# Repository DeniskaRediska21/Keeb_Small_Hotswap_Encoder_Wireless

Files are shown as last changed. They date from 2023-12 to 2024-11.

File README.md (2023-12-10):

# Split Ergo Ortholinear Hotswap Keyboard 

This project attempts to create easelly reproducible split ortholinear  hotswap mechanical
keyboard. 

Gimmics: 
+ This design doesn't require any diodes
+ Uses PiPico as MC, runs on CircuitPython
+ Key layouts are changed by dragging a file onto PiPicos storrage
+ Halves are connected through TypeC
+ PCB fits into 100x100mm square, so it is very cheap to order from Chineese manifacturers

# Gallery

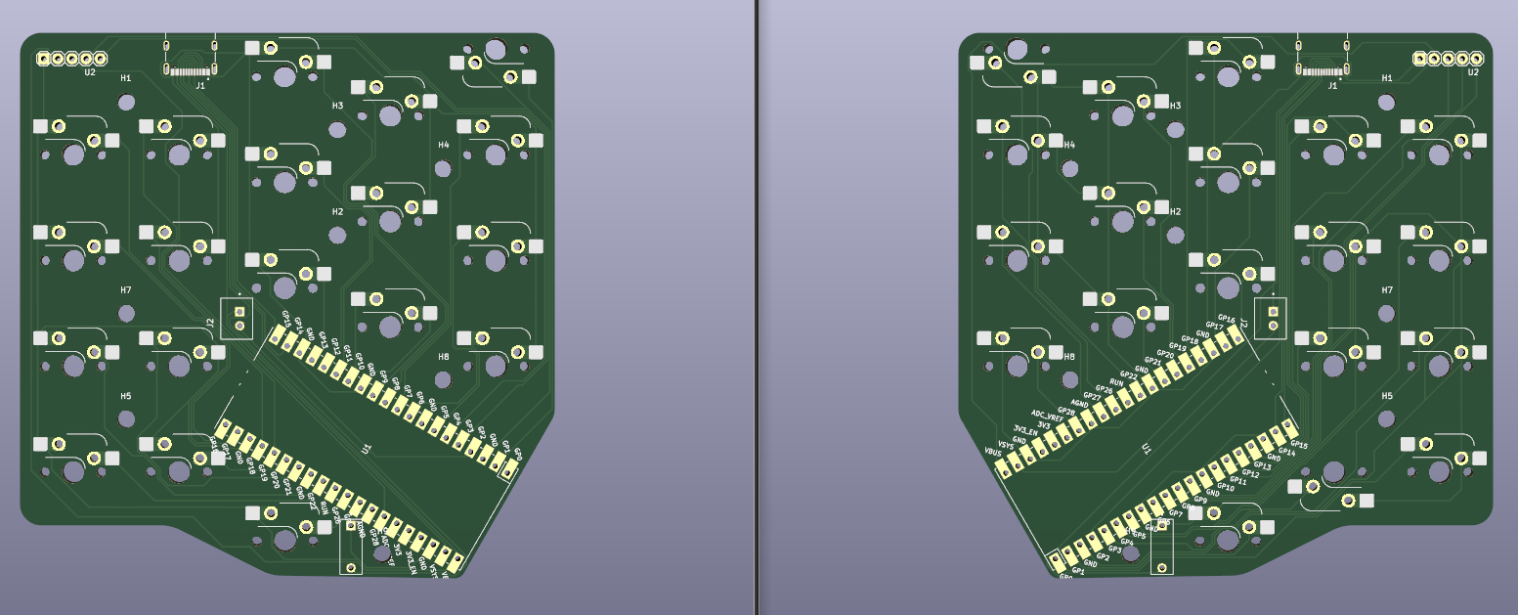
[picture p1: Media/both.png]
PCB


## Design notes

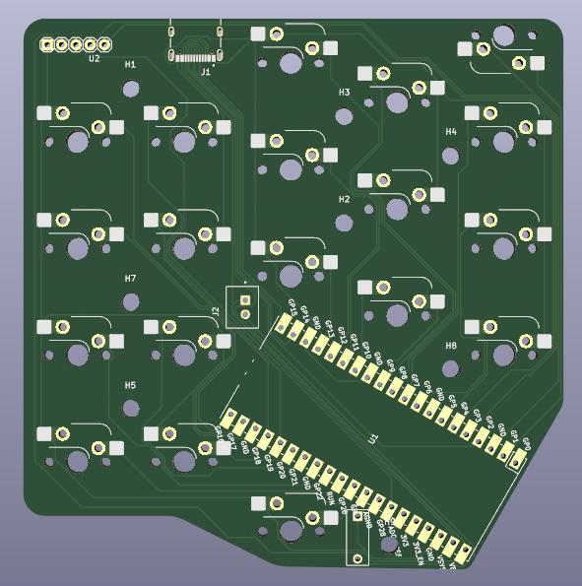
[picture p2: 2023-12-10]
Media/left_board.png

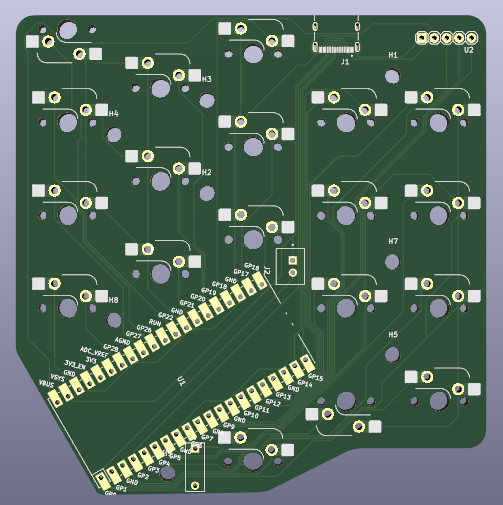
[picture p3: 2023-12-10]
Media/right.png

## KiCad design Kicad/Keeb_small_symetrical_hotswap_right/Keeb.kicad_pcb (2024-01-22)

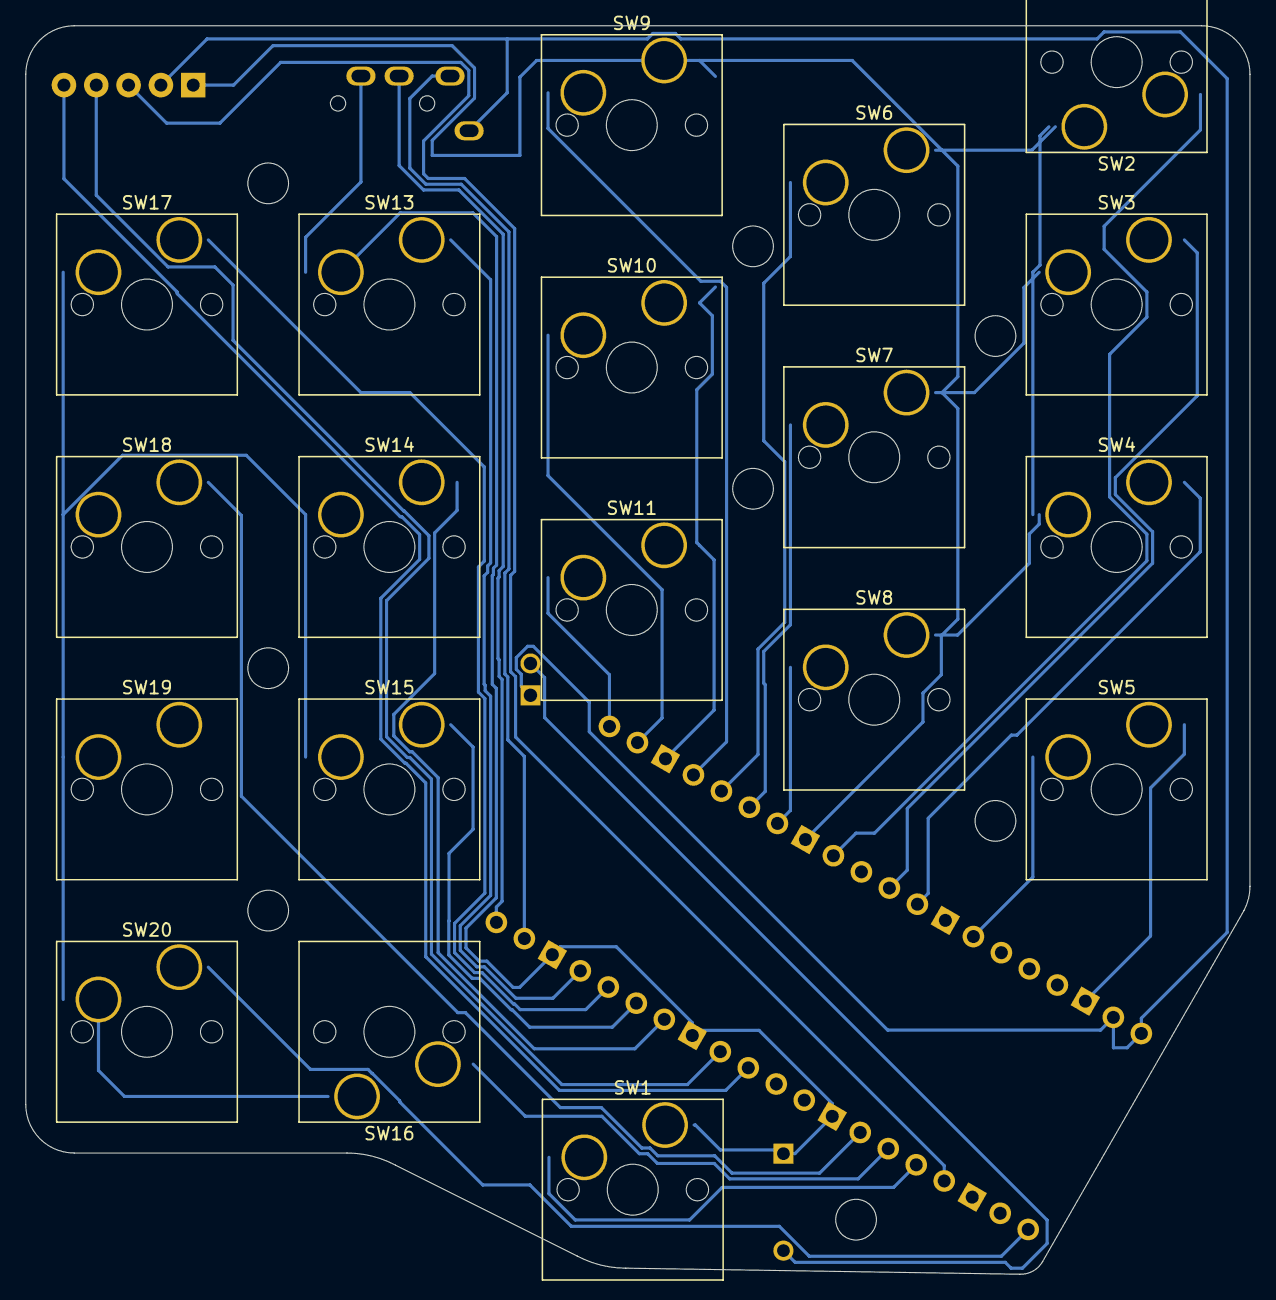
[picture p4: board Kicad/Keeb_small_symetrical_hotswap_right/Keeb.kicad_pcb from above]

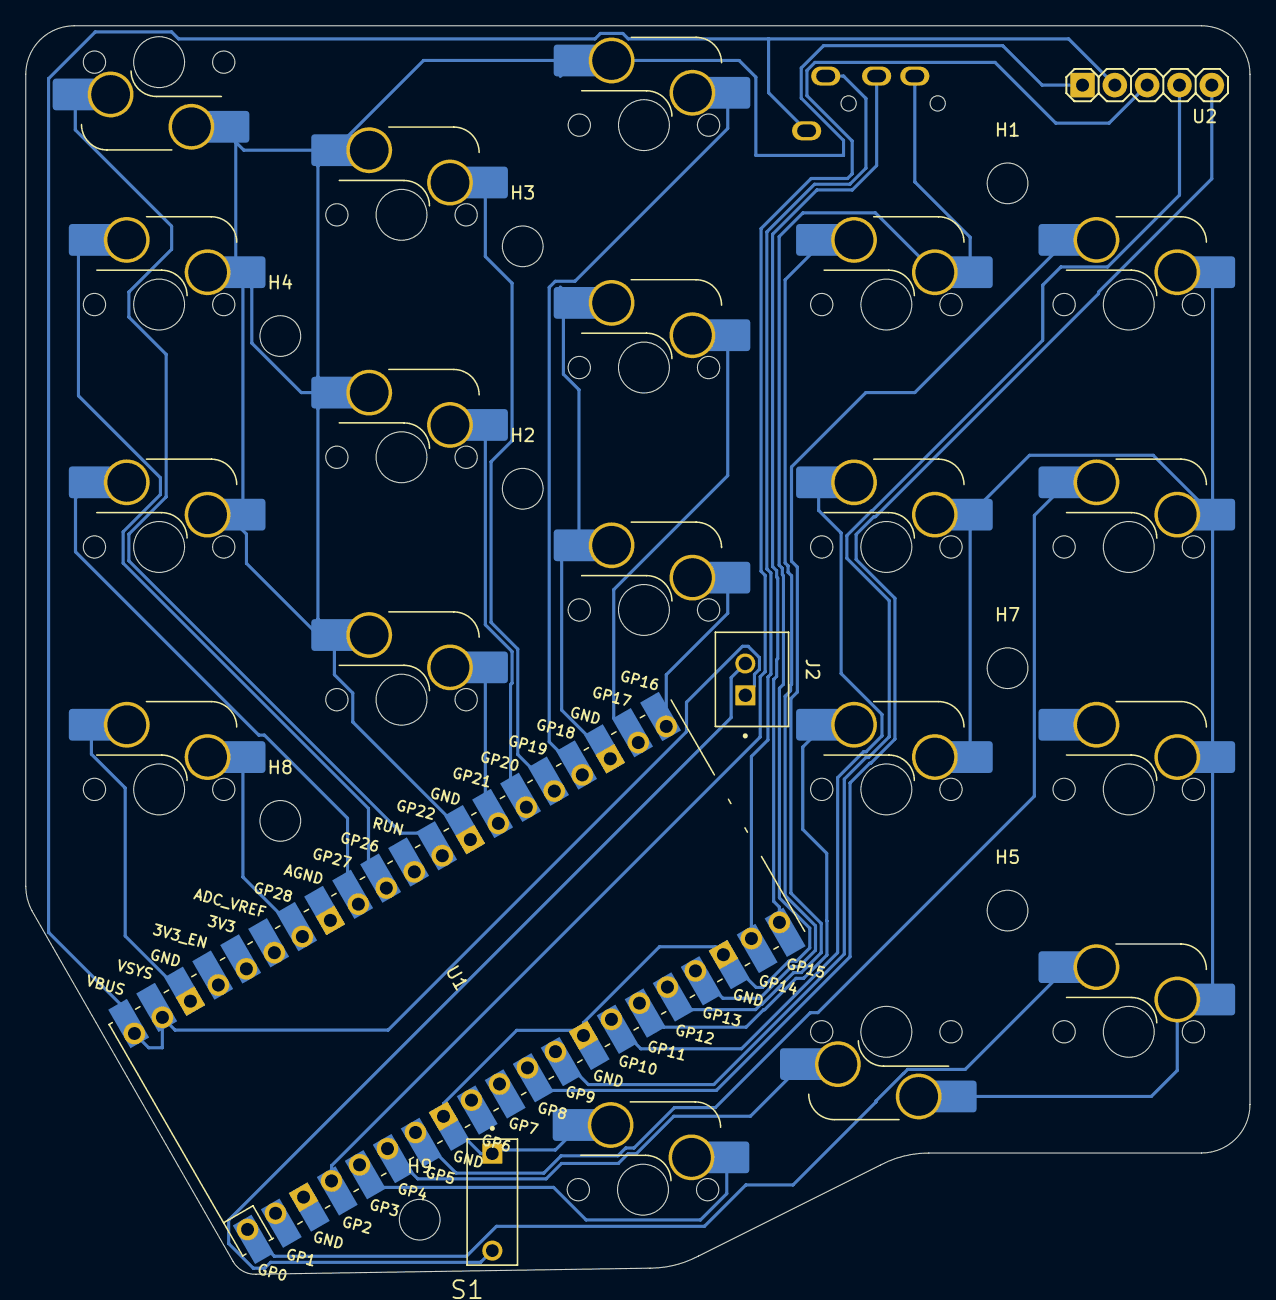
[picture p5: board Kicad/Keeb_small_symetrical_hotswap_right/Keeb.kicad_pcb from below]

Board: 2 copper layers, 96.2 x 98.1 mm, 32 parts (12 on the bottom side), 27 nets.

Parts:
H1, H2, H3, H4, H5, H7, H8, H9: MountingHole; MountingHole_3.2mm_M3
J2: B2B-XH-A_LF__SN_; JST_B2B-XH-A_LF__SN_
J3: MJ-4PP-9_MJ-4PP-9; MJ-4PP-9_no_silk
S1: DS01-254-L-01BE; SW_DS01-254-L-01BE
SW1, SW2, SW3, SW4, SW5, SW6, SW7, SW8, SW9, SW10, SW11, SW13, SW14, SW15, SW16, SW17, SW18, SW19, SW20: CherryMX; Hotswap_MX_Plated_1.00u
U1: Pico; RPi_Pico_SMD_TH_NO_BACK_HOLES
U2: KY-040; KY-040-PORT

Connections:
0: SW20.2, U1.1 (GPIO0)
1: SW19.2, U1.2 (GPIO1)
2: U1.4 (GPIO2), U2.SW
3: SW1.1, U1.5 (GPIO3)
3v3: J2.1, J3.1 (A), U1.39 (VSYS), U1.40 (VBUS), U2.VCC
4: SW16.1, U1.6 (GPIO4)
5: SW18.2, U1.7 (GPIO5)
8: U1.11 (GPIO8), U2.CLK
9: U1.12 (GPIO9), U2.DT
10: SW14.2, U1.14 (GPIO10)
11: SW15.2, U1.15 (GPIO11)
12: SW17.2, U1.16 (GPIO12)
13: SW13.2, U1.17 (GPIO13)
14: J3.4 (D), U1.19 (GPIO14)
15: J3.3 (C), U1.20 (GPIO15)
16: SW11.1, U1.21 (GPIO16)
17: SW10.1, U1.22 (GPIO17)
18: SW9.1, U1.24 (GPIO18)
19: SW6.1, U1.25 (GPIO19)
20: SW7.1, U1.26 (GPIO20)
21: SW8.1, U1.27 (GPIO21)
22: SW2.1, U1.29 (GPIO22)
26: SW3.2, U1.31 (GPIO26_ADC0)
27: SW4.2, U1.32 (GPIO27_ADC1)
28: SW5.1, U1.34 (GPIO28_ADC2)
GND: J3.2 (B), S1.1A, SW1.2, SW2.2, SW3.1, SW4.1, SW5.2, SW6.2, SW7.2, SW8.2, SW9.2, SW10.2, SW11.2, SW13.1, SW14.1, SW15.1, SW16.2, SW17.1, SW18.1, SW19.1, SW20.1, U1.3 (GND), U1.8 (GND), U1.13 (GND), U1.18 (GND), U1.23 (GND), U1.28 (GND), U1.33 (AGND), U1.38 (GND), U2.GND
unnamed: J2.2, S1.1B

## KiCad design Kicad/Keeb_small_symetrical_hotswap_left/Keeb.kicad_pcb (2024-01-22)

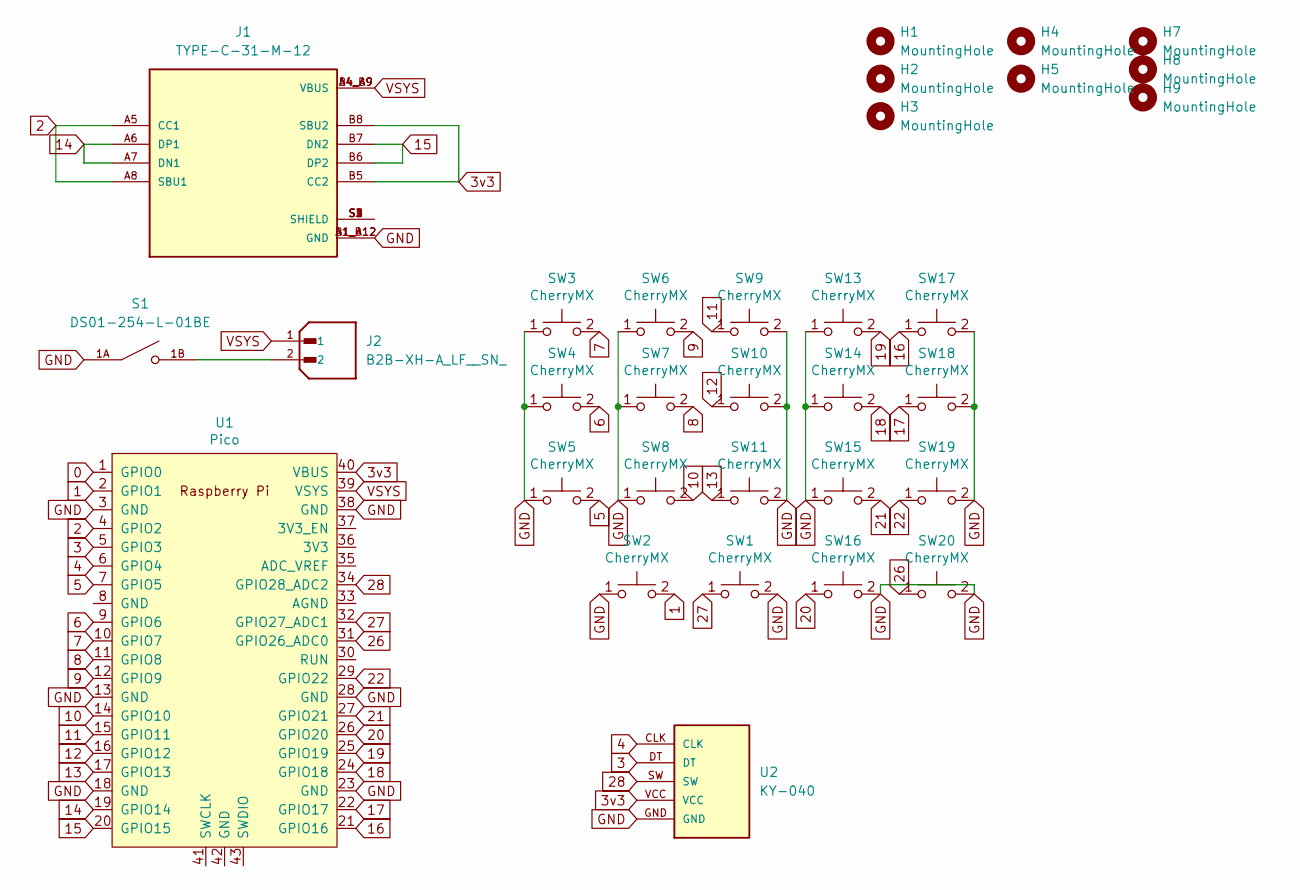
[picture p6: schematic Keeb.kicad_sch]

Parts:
H1, H2, H3, H4, H5, H7, H8, H9: MountingHole; MountingHole_3.2mm_M3
J1: TYPE-C-31-M-12; HRO_TYPE-C-31-M-12; PARTREV 2020.12.08
J2: B2B-XH-A_LF__SN_; JST_B2B-XH-A_LF__SN_; PARTREV N/A
S1: DS01-254-L-01BE; SW_DS01-254-L-01BE; PARTREV 1.0
SW1, SW2, SW3, SW4, SW5, SW6, SW7, SW8, SW9, SW10, SW11, SW13, SW14, SW15, SW16, SW17, SW18, SW19, SW20: CherryMX; Hotswap_MX_Plated_1.00u_Smaller_hole
U1: Pico; RPi_Pico_SMD_TH_NO_BACK_HOLES
U2: KY-040; KY-040-PORT

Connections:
0: U1.1 (GPIO0)
1: SW2.2, U1.2 (GPIO1)
2: J1.A5 (CC1), J1.A8 (SBU1), U1.4 (GPIO2)
3: U1.5 (GPIO3), U2.DT
3v3: J1.B5 (CC2), J1.B8 (SBU2), U1.40 (VBUS), U2.VCC
4: U1.6 (GPIO4), U2.CLK
5: SW5.2, U1.7 (GPIO5)
6: SW4.2, U1.9 (GPIO6)
7: SW3.2, U1.10 (GPIO7)
8: SW7.2, U1.11 (GPIO8)
9: SW6.2, U1.12 (GPIO9)
10: SW8.2, U1.14 (GPIO10)
11: SW9.1, U1.15 (GPIO11)
12: SW10.1, U1.16 (GPIO12)
13: SW11.1, U1.17 (GPIO13)
14: J1.A6 (DP1), J1.A7 (DN1), U1.19 (GPIO14)
15: J1.B6 (DP2), J1.B7 (DN2), U1.20 (GPIO15)
16: SW17.1, U1.21 (GPIO16)
17: SW18.1, U1.22 (GPIO17)
18: SW14.2, U1.24 (GPIO18)
19: SW13.2, U1.25 (GPIO19)
20: SW16.1, U1.26 (GPIO20)
21: SW15.2, U1.27 (GPIO21)
22: SW19.1, U1.29 (GPIO22)
26: SW20.1, U1.31 (GPIO26_ADC0)
27: SW1.1, U1.32 (GPIO27_ADC1)
28: U1.34 (GPIO28_ADC2), U2.SW
GND: J1.A1_B12 (GND), J1.B1_A12 (GND), S1.1A, SW1.2, SW2.1, SW3.1, SW4.1, SW5.1, SW6.1, SW7.1, SW8.1, SW9.2, SW10.2, SW11.2, SW13.1, SW14.1, SW15.1, SW16.2, SW17.2, SW18.2, SW19.2, SW20.2, U1.3 (GND), U1.13 (GND), U1.18 (GND), U1.23 (GND), U1.28 (GND), U1.38 (GND), U2.GND
unnamed: J1.S1 (SHIELD), J1.S2 (SHIELD), J1.S3 (SHIELD), J1.S4 (SHIELD)
unnamed: J2.2, S1.1B
VSYS: J1.A4_B9 (VBUS), J1.B4_A9 (VBUS), J2.1, U1.39 (VSYS)

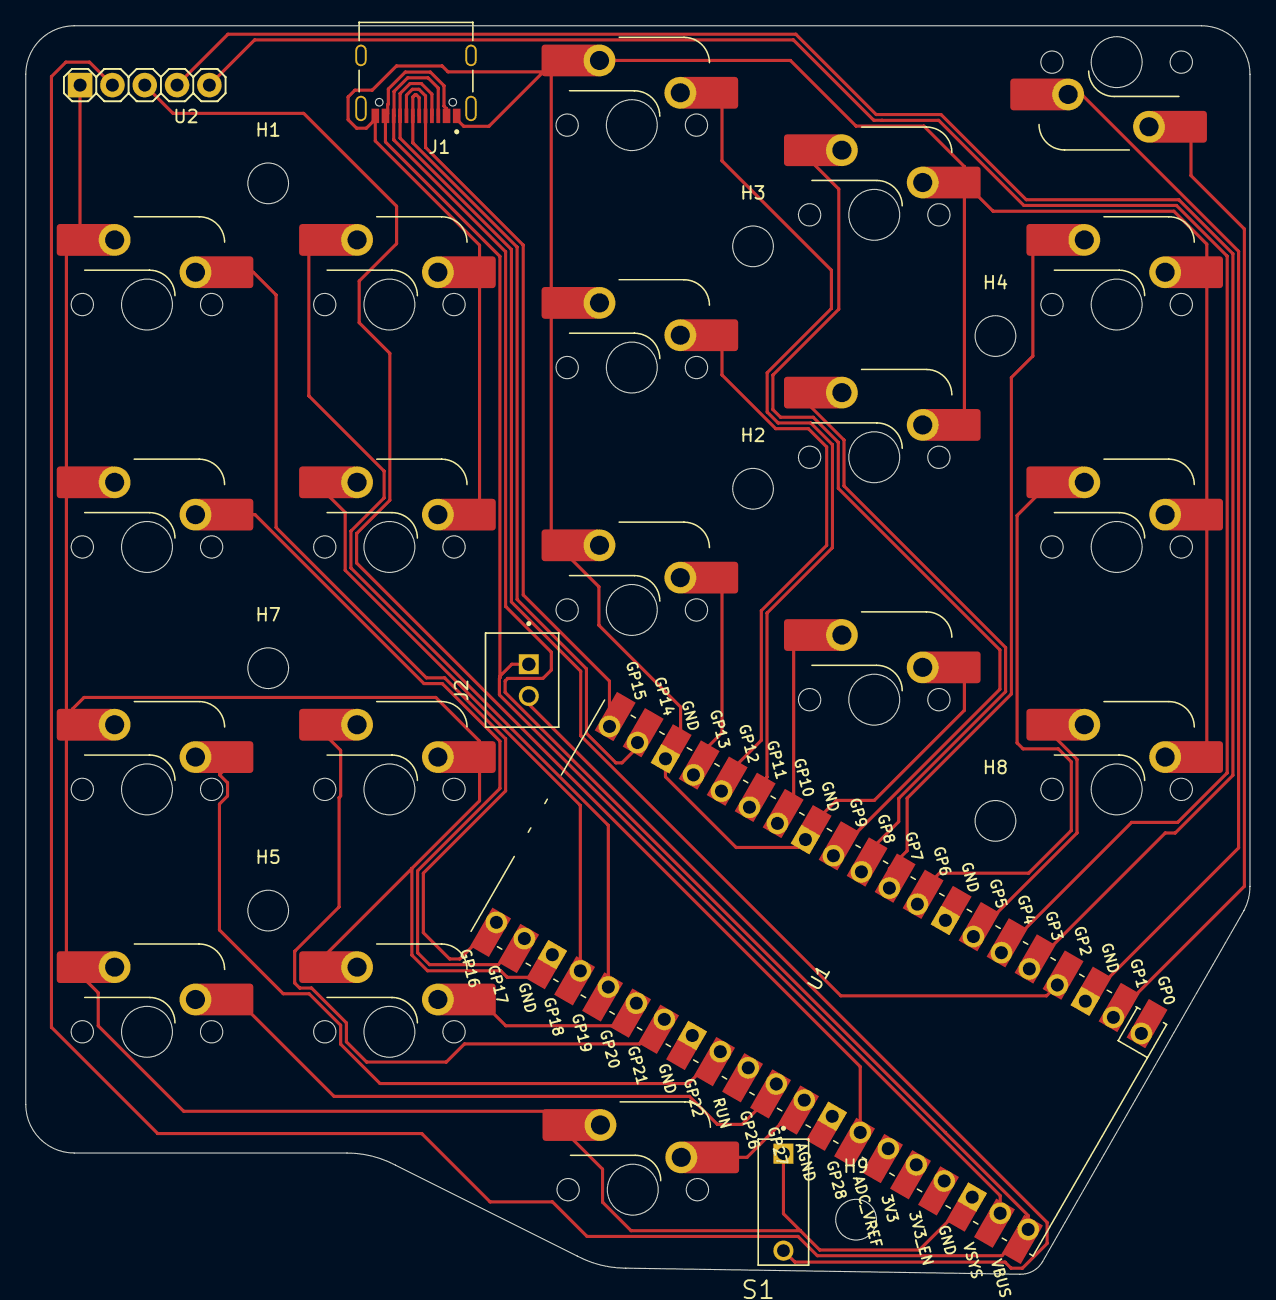
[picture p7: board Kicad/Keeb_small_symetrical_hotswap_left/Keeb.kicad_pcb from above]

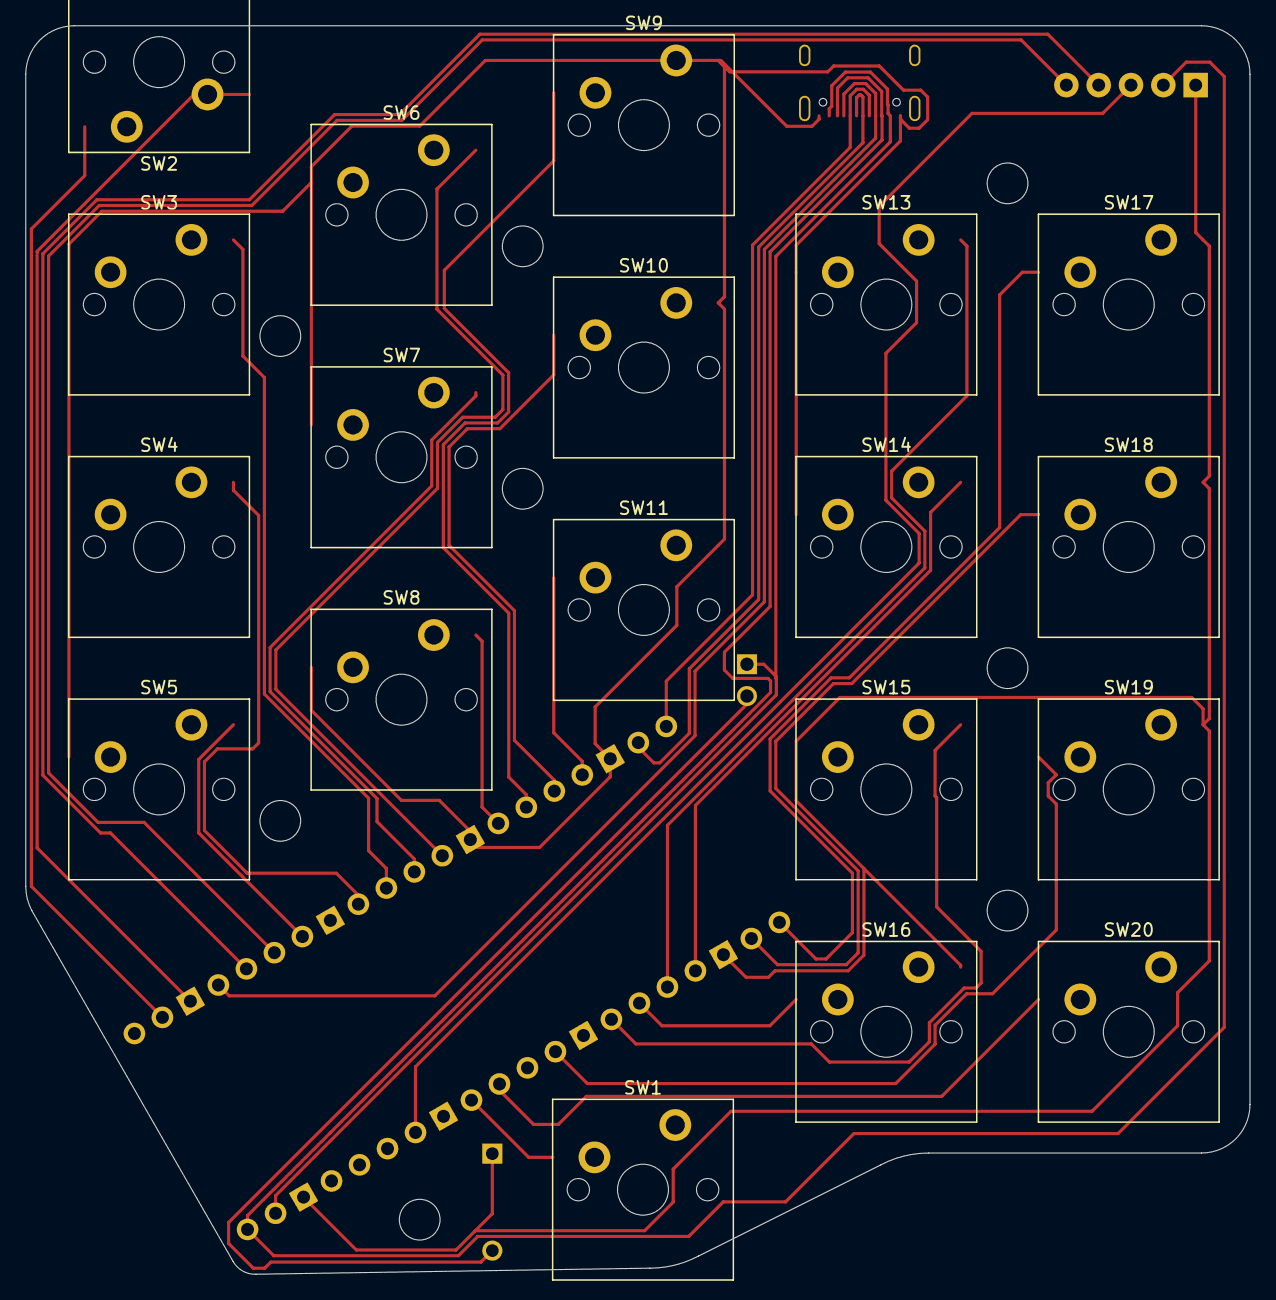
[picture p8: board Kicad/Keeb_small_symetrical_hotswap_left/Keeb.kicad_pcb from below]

Board: 2 copper layers, 96.2 x 98.1 mm, 32 parts (19 on the bottom side), 30 nets.

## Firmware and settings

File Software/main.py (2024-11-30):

import board
import digitalio 
from kmk.modules.oneshot import OneShot
from kb import KMKKeyboard, isRight
from storage import getmount
from kmk.keys import KC
from kmk.modules.layers import Layers
from kmk.modules.split import Split, SplitSide, SplitType
from kmk.modules.mouse_keys import MouseKeys
from kmk.extensions.media_keys import MediaKeys
from kmk.handlers.sequences import simple_key_sequence
from kmk.modules.encoder import EncoderHandler
from kmk.modules.holdtap import HoldTap
from kmk.modules.tapdance import TapDance
from kmk.modules.capsword import CapsWord


keyboard = KMKKeyboard()

keyboard.tap_time = 100
keyboard.extensions.append(MediaKeys())


layers = Layers()

encoder_handler = EncoderHandler()


split_side = SplitSide.RIGHT if isRight else SplitSide.LEFT



# data_pin = board.GP2

data_pin = board.GP14 if split_side == SplitSide.LEFT else board.GP14



# data_pin2 = board.GP2 if split_side == SplitSide.LEFT else board.GP15


                 
        

split = Split(
#     split_side=split_side,
    split_type=SplitType.UART,
#     split_type=SplitType.BLE,
    split_flip=False,
    data_pin=data_pin,
#     data_pin2=data_pin2,
    uart_flip = True,
    use_pio = True,
)

keyboard.modules = [layers, split, MouseKeys(),OneShot(), encoder_handler, HoldTap(), TapDance(), CapsWord()]

# Select line 

SEL_LINE = simple_key_sequence(

        (

                KC.END,

                KC.LSHIFT(KC.HOME)

        )

)

 

G_SHIFT_CAPS = KC.TD(KC.HT(KC.G, KC.LSHIFT, tap_time=200, prefer_hold=False), KC.CW, tap_time=80)
G_SHIFT = KC.HT(KC.G, KC.LSHIFT, tap_time=200, prefer_hold=False)
H_SHIFT = KC.HT(KC.H, KC.RSHIFT, tap_time=200, prefer_hold=False)

LOWER =KC.LT(1,KC.OS(KC.MO(1),tap_time=1000))

RAISE =KC.LT(2,KC.OS(KC.MO(2),tap_time=1000))

Zoom_in = KC.LCTRL(KC.PPLS)
Zoom_out = KC.LCTRL(KC.MINUS)

OS_LCTL = KC.OS(KC.LCTL, tap_time=None)
keyboard.keymap = [

    [  #QWERTY
                                           KC.RALT,			 KC.TAB,\

        KC.Q,    KC.W,    KC.E,    KC.R,    KC.T,                        KC.Y,    KC.U,    KC.I,    KC.O,   KC.P,\

        KC.A,    KC.S,    KC.D,    KC.F,    G_SHIFT_CAPS,                        H_SHIFT,    KC.J,    KC.K,    KC.L, KC.BSPC,\

        KC.Z,    KC.X,    KC.C,    KC.V,    KC.COMM,                        KC.DOT,    KC.N, KC.M,  KC.B, KC.ESC,\

                          KC.LSFT,   LOWER,KC.SPACE,              		 KC.ENT,     RAISE,   KC.LCTL,\
                          
                          KC.NO, Zoom_in, Zoom_out, 				KC.MW_UP, KC.MW_DOWN, KC.NO, 
                          

    ],

    [  #LOWER	
                                           					       KC.RALT, 			KC.TAB,\

        KC.N1,          KC.N2,           KC.N3,           	 KC.N4,                KC.N5,                           KC.N6,      KC.N7,     KC.N8,     KC.N9,    KC.N0,\

        KC.LCTL(KC.A),  KC.LCTL(KC.S),   KC.LCTL(KC.RALT(KC.T)), KC.QUES,              KC.LCTL(KC.V),                   KC.N0,      KC.LEFT,   KC.DOWN,     KC.UP, KC.RIGHT,\

        KC.LCTL(KC.Z),  KC.LCTL(KC.X),   KC.LCTL(KC.INSERT),     KC.LSFT(KC.INSERT),   KC.LCTL(KC.C),                   KC.GRAVE,   KC.LABK,   KC.PIPE,   KC.RABK,  KC.SLSH,\
 
                                         KC.LSFT,                KC.NO,   KC.SPACE,                                      KC.ENT,      KC.NO,    KC.LCTL,\
                                         
                          KC.NO, Zoom_in, Zoom_out, 				KC.VOLU, KC.VOLD, KC.NO, 

    ],

    [  #RAISE
                                              KC.RALT,			    KC.TAB,\

        KC.EXLM,   KC.AT, KC.HASH,  KC.DLR,   KC.PERC,                      KC.CIRC, KC.AMPR, KC.ASTR, KC.LPRN, KC.RPRN,\

        KC.F2,     KC.F5,   KC.F9,  KC.QUOT,  KC.SCLN,                      KC.UNDS,  KC.EQL, KC.LCBR, KC.RCBR, KC.DEL,\

        KC.F12,    KC.F11,  KC.F10, KC.DQUO,  KC.COLON,                     KC.MINS, KC.PLUS, KC.LBRC, KC.RBRC, KC.BSLS,\

                          KC.LSFT,   KC.NO,   KC.SPACE,                     KC.ENT,      KC.NO,    KC.LCTL,\
                                         
                          KC.NO, Zoom_in, Zoom_out, 				KC.MW_UP, KC.MW_DOWN, KC.NO,

    ]

]


#split_side == SplitSide.LEFT
#encoder_handler.pins = (
    # regular direction encoder and a button
#    (board.GP4, board.GP3, board.GP28,) if split_side == SplitSide.LEFT else (board.GP7, board.GP8, board.GP9,), # encoder #1 
#    )
#Zoom_in = KC.LCTRL(KC.EQUAL)
#Zoom_out = KC.LCTRL(KC.MINUS)
#encoder_handler.map = [((Zoom_out, Zoom_in, KC.NO),) if split_side == SplitSide.LEFT else (( KC.MW_UP, KC.MW_DOWN, KC.N0),)]





 



if __name__ == '__main__':

    keyboard.go()

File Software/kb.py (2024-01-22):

import board
import digitalio

from storage import getmount

from kmk.kmk_keyboard import KMKKeyboard as _KMKKeyboard
from kmk.scanners.keypad import KeysScanner
from kmk.scanners.encoder import RotaryioEncoder


# VBus pin config
VBUS_PIN = board.VBUS_SENSE  # RPi Pico
# VBUS_PIN = board.GP29      # WeAct RP2040 + resistors on Piantor PCB

# split side detection using vbus sense
# vbus = digitalio.DigitalInOut(VBUS_PIN)
# vbus.direction = digitalio.Direction.INPUT
# isRight = False if vbus.value == True else False
# isRight = False


# alternate option: set side based on drive names
name = str(getmount('/').label)
isRight = True if name.endswith('R') else False

# GPIO to key mapping, Left
_KEY_CFG_LEFT = [
board.GP1,
board.GP7,board.GP9,board.GP11,board.GP19,board.GP16,
board.GP6,board.GP8,board.GP12,board.GP18,board.GP17,
board.GP5,board.GP10,board.GP13,board.GP21,board.GP22,
board.GP27,board.GP20,board.GP26,board.GP28
]

# GPIO to key mapping, Left
_KEY_CFG_RIGHT = [
board.GP22,
board.GP12,board.GP13,board.GP18,board.GP19,board.GP26,
board.GP5,board.GP10,board.GP17,board.GP20,board.GP27,
board.GP3,board.GP11,board.GP16,board.GP21,board.GP28,
board.GP0,board.GP4,board.GP1,board.GP9
]


class KMKKeyboard(_KMKKeyboard):
    def __init__(self):
        # create and register the scanner
        self.matrix = [KeysScanner(
            pins = _KEY_CFG_RIGHT if isRight == True else _KEY_CFG_LEFT
        ),
        RotaryioEncoder(
            pin_a= board.GP7 if isRight == True else board.GP4,
            pin_b=board.GP8 if isRight == True else board.GP3,)
        ]



    coord_mapping = [
    			 0,   22,
         1,  2,  3,  4,  5,   23, 24, 25, 26, 27,
         6,  7,  8,  9, 10,   28, 29, 30, 31, 32,
        11, 12, 13, 14, 15,   33, 34, 35, 36, 37,
                16, 17, 18,   38, 39, 40, 
                19, 21, 20,   43, 42, 41
    ]

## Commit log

2023-12-06 added encoder
    [Keeb.kicad_pcb, Keeb.kicad_sch]
2023-12-07 moved some traces
    [Keeb.kicad_pcb]
2023-12-08 Managed to add a button, optimised tracks, switched some connections around
    [Keeb.kicad_pcb, Keeb.kicad_sch]
2023-12-08 Worked a bit on the edge-cuts
    [Keeb.kicad_pcb]
2023-12-08 Addedthe photo of board
2023-12-08 Updated a PiPico footprint
    [Keeb-B_Mask.gbr, Keeb-Edge_Cuts.gbr, Keeb-F_Cu.gbr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]
2023-12-08 added more fillets
    [Keeb.kicad_pcb]
2023-12-08 added a connectior for the battery
    [Keeb.kicad_pcb, Keeb.kicad_sch]
2023-12-08 added a on/off
    [Keeb.kicad_pcb, Keeb.kicad_sch]
2023-12-10 Switched footprint to copper plater one to give an opiton of soldering switches directly
    [Keeb.kicad_pcb, Keeb.kicad_sch]
2023-12-10 Almost dome with right half
    [Keeb-B_Mask.gbr, Keeb-Edge_Cuts.gbr, Keeb-F_Cu.gbr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]
2023-12-10 Fixedright board
    [Keeb.kicad_pcb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]
2023-12-10 Added gerbers
    [Keeb-B_Mask.gbr, Keeb-Edge_Cuts.gbr, Keeb-F_Cu.gbr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]
2024-01-22 Added software
    [Keeb-B_Cu.gbr, Keeb-B_Mask.gbr, Keeb-Edge_Cuts.gbr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]
2024-01-22 Implemented encoders on the split halves
    [Keeb.kicad_pcb]
